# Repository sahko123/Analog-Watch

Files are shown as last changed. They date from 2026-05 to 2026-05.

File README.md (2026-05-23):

# Analog Watch

A watch that tells time using an analog voltmeter needle driven by a DAC. No screen. No hands. Just vibes and a carefully calibrated lookup table.

Featured in: **[I Built a Digital Watch With No Screen](https://youtu.be/faMIdIe0c6w)** (YOUTUBE LINK)

---

## What is this?

It's a watch. Technically. A Raspberry Pi Pico reads the time and drives an MCP4726 DAC, which pushes a voltage to a panel meter whose needle sweeps to represent whatever time-related concept you've most recently asked it about.

By default it shows seconds. Because why would you want to know the hours.

---

## How to read the time

Press a button.

| Button | Single Press | Double Click |
|---|---|---|
| Top | Hours | Date |
| Mid | Month | Seconds |
| Low | Day of week | — |

The needle will swing to the correct position. Stare at it. Contemplate what you've built.

---

## Repo contents

| Path | What's in it |
|---|---|
| `ANALCLOCK_REV0_5.ino` | Arduino sketch (RP2040) |
| `analclock v1/` | KiCad PCB project — main board revisions 1 & 2 |
| `analclock v1/analog_dial/` | KiCad PCB project — the meter dial board |
| `analclock v1/gerberv1/` | Gerber files for the main board |
| `analclock v1/analog_dial/analogdial1gerbers/` | Gerber files for the dial board |
| `*.svg` / `*.dxf` | Watch face artwork |
| `*.step` / `*.stl` / `*.f3d` | 3D printed parts |

---

## Calibration

The meter needle is non-linear, so the firmware uses a cubic polynomial LUT to correct for this. You can tune it over serial:

```
dac <value>      — hold needle at a fixed DAC value
max <value>      — set full-scale and rebuild the LUT
set <idx> <val>  — manually poke a LUT entry
lut              — print current LUT
tz <offset>      — set UTC offset in hours
<unix timestamp> — set the time
```

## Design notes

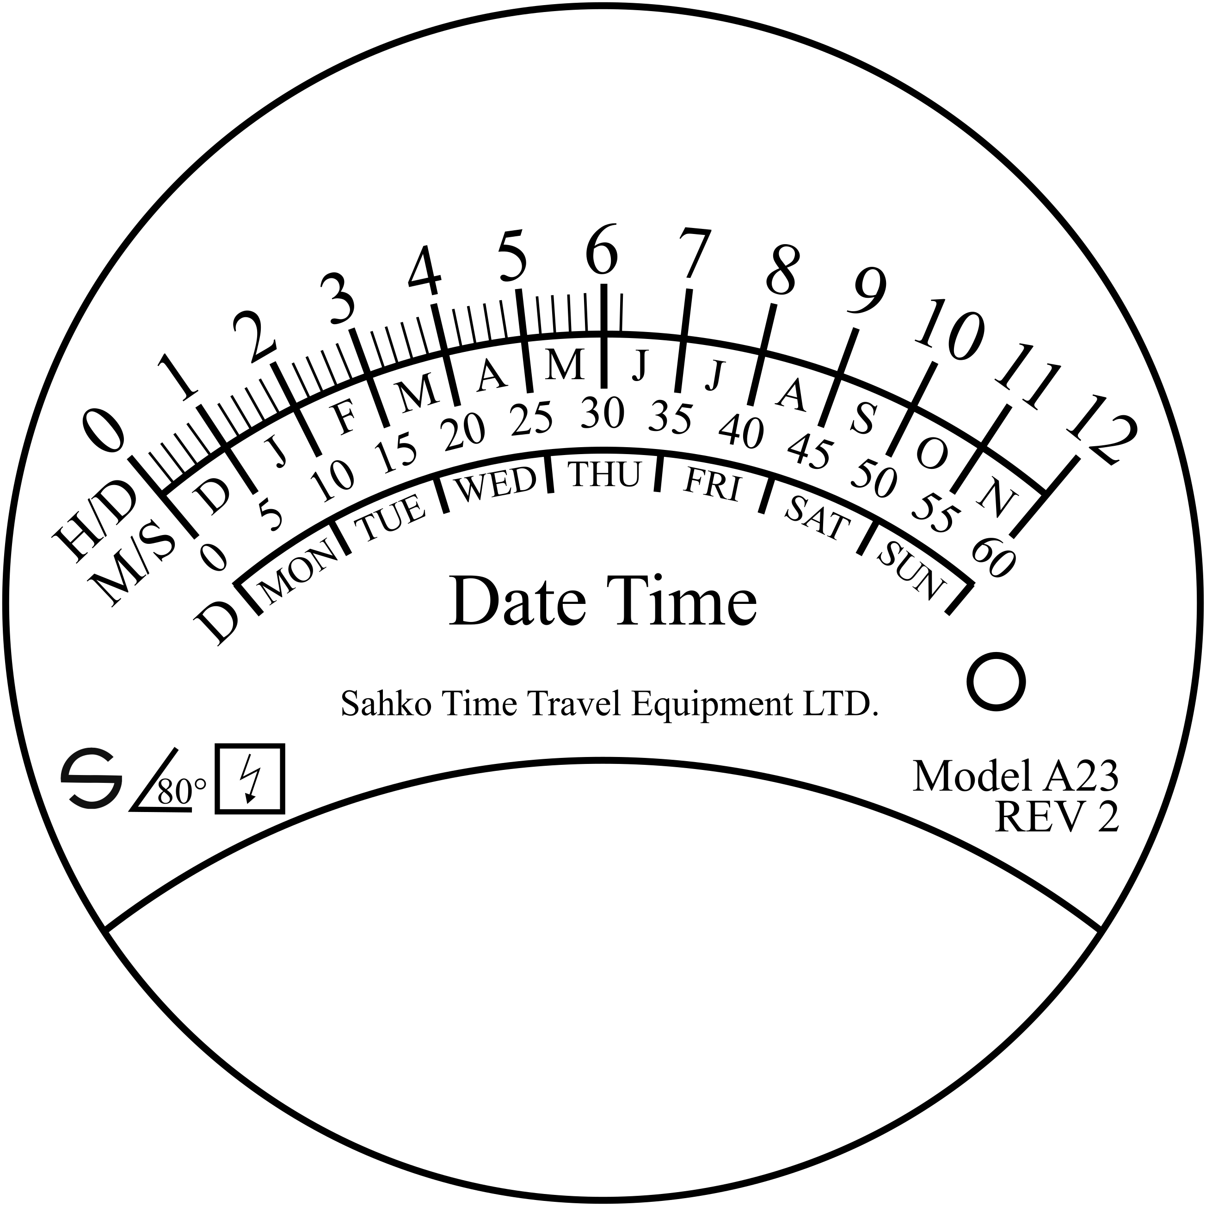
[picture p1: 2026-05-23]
analog watch 3.png

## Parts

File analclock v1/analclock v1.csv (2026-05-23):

Source: | C:\Users\Alexander Gorovenko\Desktop\Video Workbook\The Analog Watch\analclock v1\analclock v1.kicad_sch
Date: | 05/08/2023 12:25:58 AM
Tool: | Eeschema 7.0.1
Generator: | C:\Program Files\KiCad\7.0\bin\scripting\plugins/bom_csv_grouped_by_value_with_fp.py
Component Count: | 48
Ref | Qnty | Value | Cmp name | Footprint | Description | Vendor | DNP
C1, C2 | 2 | 15pF | C | Capacitor_SMD:C_0201_0603Metric_Pad0.64x0.40mm_HandSolder | Unpolarized capacitor
C3, C4, C5, C6, C7, C10, C11, C12, C13, C14, C15 | 11 | C | C | Capacitor_SMD:C_0201_0603Metric_Pad0.64x0.40mm_HandSolder | Unpolarized capacitor
C8, C9 | 2 | C | C | Capacitor_SMD:C_0402_1005Metric | Unpolarized capacitor
E1 | 1 | B+ | Conn_01x01_Pin | TestPoint:TestPoint_Pad_2.0x2.0mm | Generic connector, single row, 01x01, script generated
E2 | 1 | B- | Conn_01x01_Pin | TestPoint:TestPoint_Pad_2.0x2.0mm | Generic connector, single row, 01x01, script generated
E3 | 1 | C+ | Conn_01x01_Pin | TestPoint:TestPoint_Pad_2.0x2.0mm | Generic connector, single row, 01x01, script generated
E4 | 1 | V+ | Conn_01x01_Pin | TestPoint:TestPoint_Pad_2.0x2.0mm | Generic connector, single row, 01x01, script generated
E5 | 1 | V- | Conn_01x01_Pin | TestPoint:TestPoint_Pad_2.0x2.0mm | Generic connector, single row, 01x01, script generated
E6, E7, E8, E9, E10, E11 | 6 | ~ | Conn_01x01_Pin | TestPoint:TestPoint_Pad_D1.0mm | Generic connector, single row, 01x01, script generated
J1 | 1 | USB_C_Receptacle_USB2.0 | USB_C_Receptacle_USB2.0 | Connector_USB:USB_C_Receptacle_GCT_USB4085 | USB 2.0-only Type-C Receptacle connector
R1, R2 | 2 | 27 | R | Resistor_SMD:R_0603_1608Metric_Pad0.98x0.95mm_HandSolder | Resistor
R3 | 1 | PROG | R | Resistor_SMD:R_0603_1608Metric_Pad0.98x0.95mm_HandSolder | Resistor
R4, R5 | 2 | R | R | Resistor_SMD:R_0603_1608Metric | Resistor
R6, R7, R8, R9 | 4 | ~ | R | Resistor_SMD:R_0402_1005Metric_Pad0.72x0.64mm_HandSolder | Resistor
SW1, SW3, SW4 | 3 | SW_Push | SW_Push | Custom:EVQP7A | Push button switch, generic, two pins
SW2 | 1 | SW_Push | SW_Push | Custom:PTS636 | Push button switch, generic, two pins
U1 | 1 | RP2040 | RP2040 | Package_DFN_QFN:QFN-56-1EP_7x7mm_P0.4mm_EP3.2x3.2mm | A microcontroller by Raspberry Pi
U2 | 1 | MCP4726 | MCP4726 | Package_TO_SOT_SMD:SOT-23-6
U3 | 1 | ~ | BMM350 | Custom:BMM350
U4, U5, U6 | 3 | ~ | AP2127 | Package_TO_SOT_SMD:TSOT-23-5
U7 | 1 | W25Q32JVSS | W25Q32JVSS | Custom:uson8 | 32Mb Serial Flash Memory, Standard/Dual/Quad SPI, SOIC-8
Y2 | 1 | Crystal_GND24 | Crystal_GND24 | PCM_Crystal_Handsoldering_AKL:Crystal_SMD_Abracon_ABM8G-4Pin_3.2x2.5mm | Four pin crystal, GND on pins 2 and 4

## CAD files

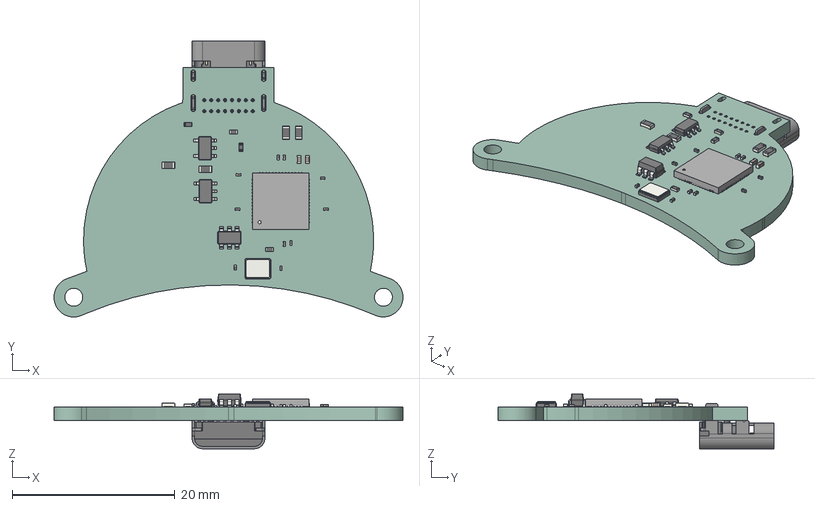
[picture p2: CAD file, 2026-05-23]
analclock v1/analclock v1.step
42.8 x 33.9 x 6.70 mm
R_0603_1608Metric x 4
QFN_56_1EP_7x7mm_P04mm_EP32x32mm
C_0201_0603Metric x 10
TSOT_23_5 x 2
C_0402_1005Metric x 2
Crystal_SMD_Abracon_ABM8G-4Pin_3.2x2.5mm
SOT_23_6
R_0402_1005Metric x 4
USB_C_Receptacle_GCT_USB4085
analclock v1_PCB

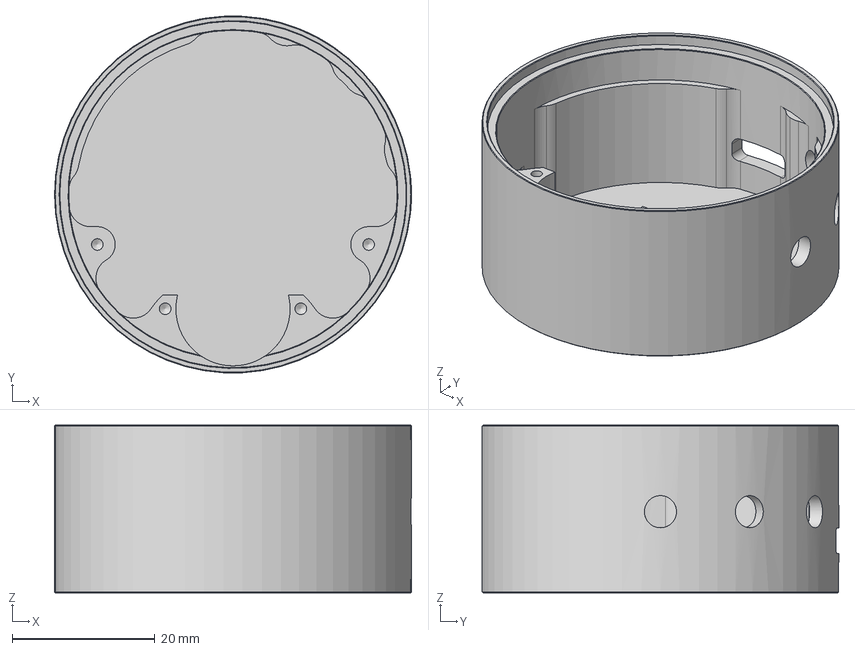
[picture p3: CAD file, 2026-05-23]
analog clock v2.step
50.0 x 49.9 x 23.5 mm

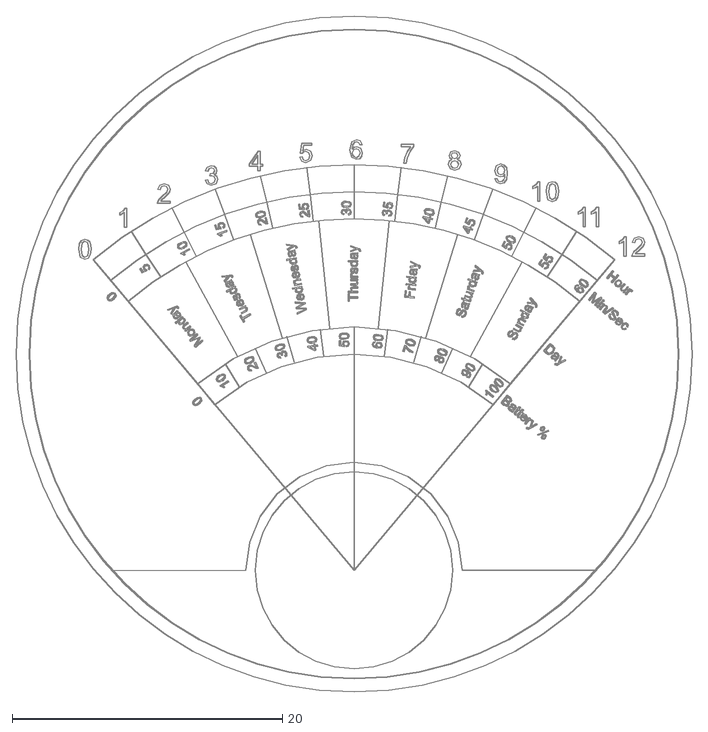
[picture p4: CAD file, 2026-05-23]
anal watch.dxf
50.0 x 50.0

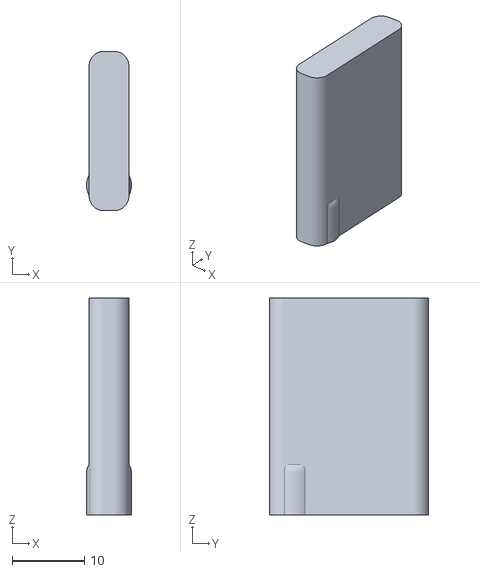
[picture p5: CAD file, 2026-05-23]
analclock v1/finger shim v4.stl
6.20 x 22.0 x 30.0

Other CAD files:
analclock v1/analog clock v2.stl
analclock v1/finger shim v4.f3d

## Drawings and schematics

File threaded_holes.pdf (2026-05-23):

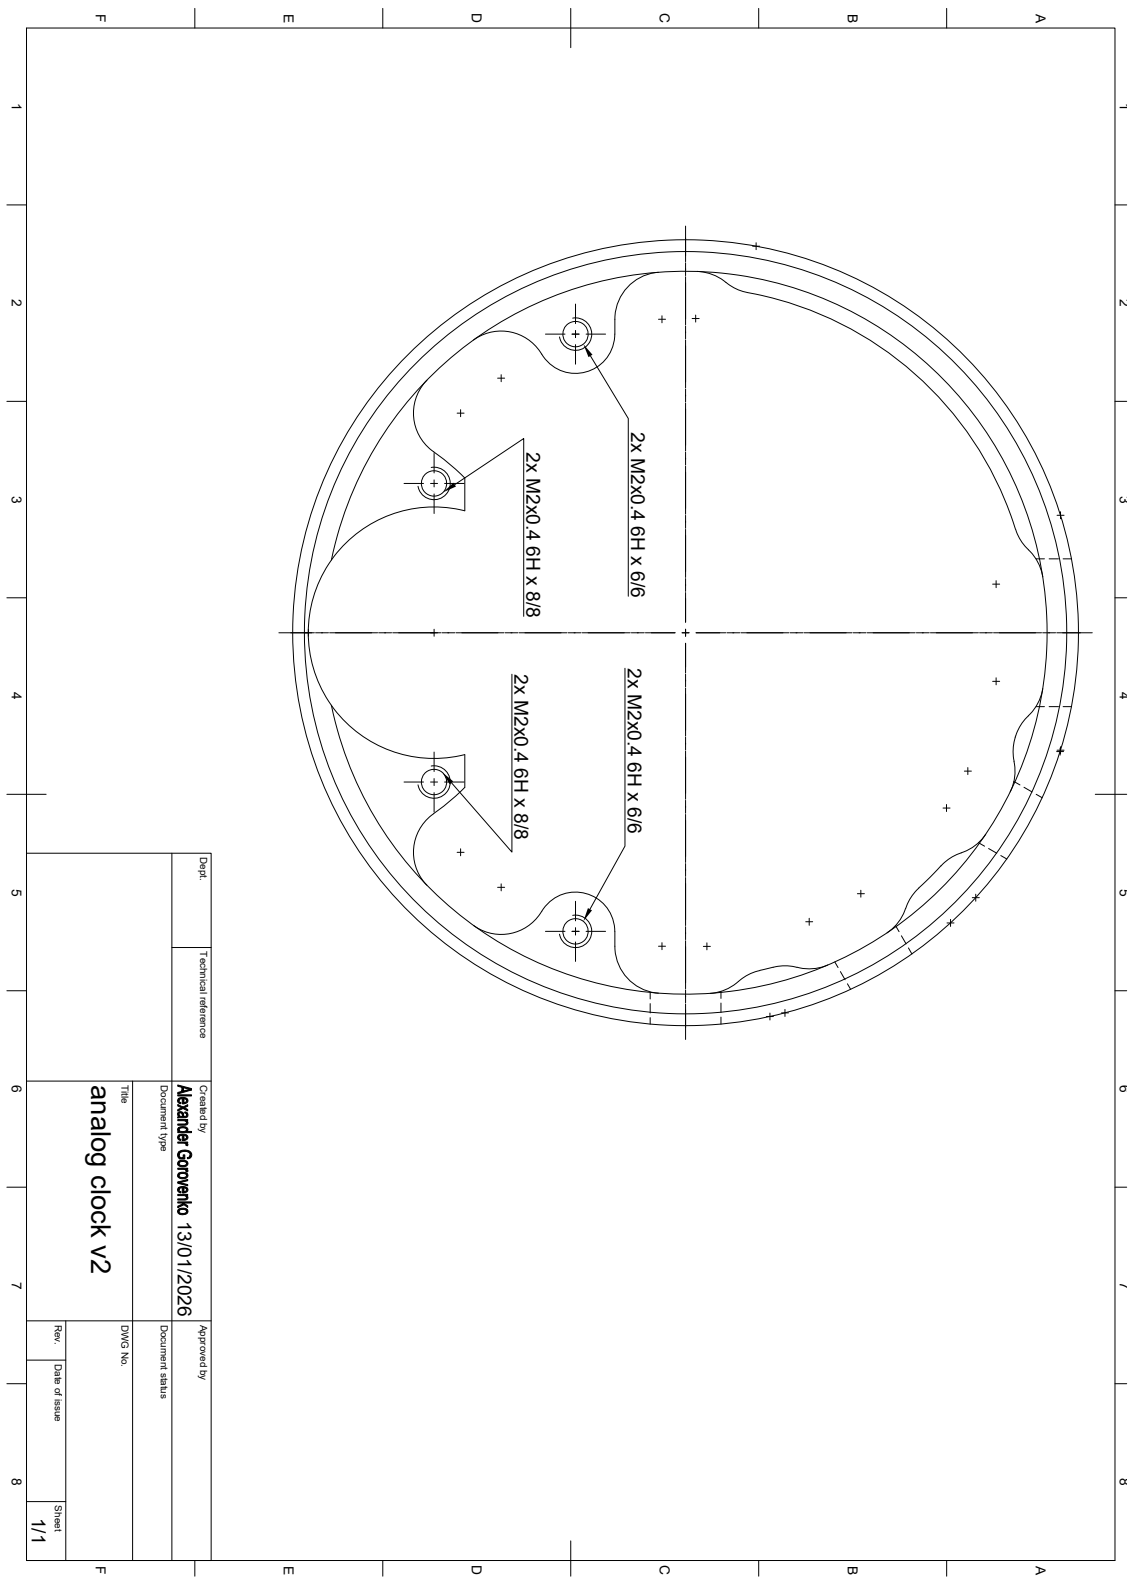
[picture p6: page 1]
analog clock v2

Dept. Technical reference Created by Approved by

Title DWG No.

Document type Document status

Rev. Date of issue Sheet

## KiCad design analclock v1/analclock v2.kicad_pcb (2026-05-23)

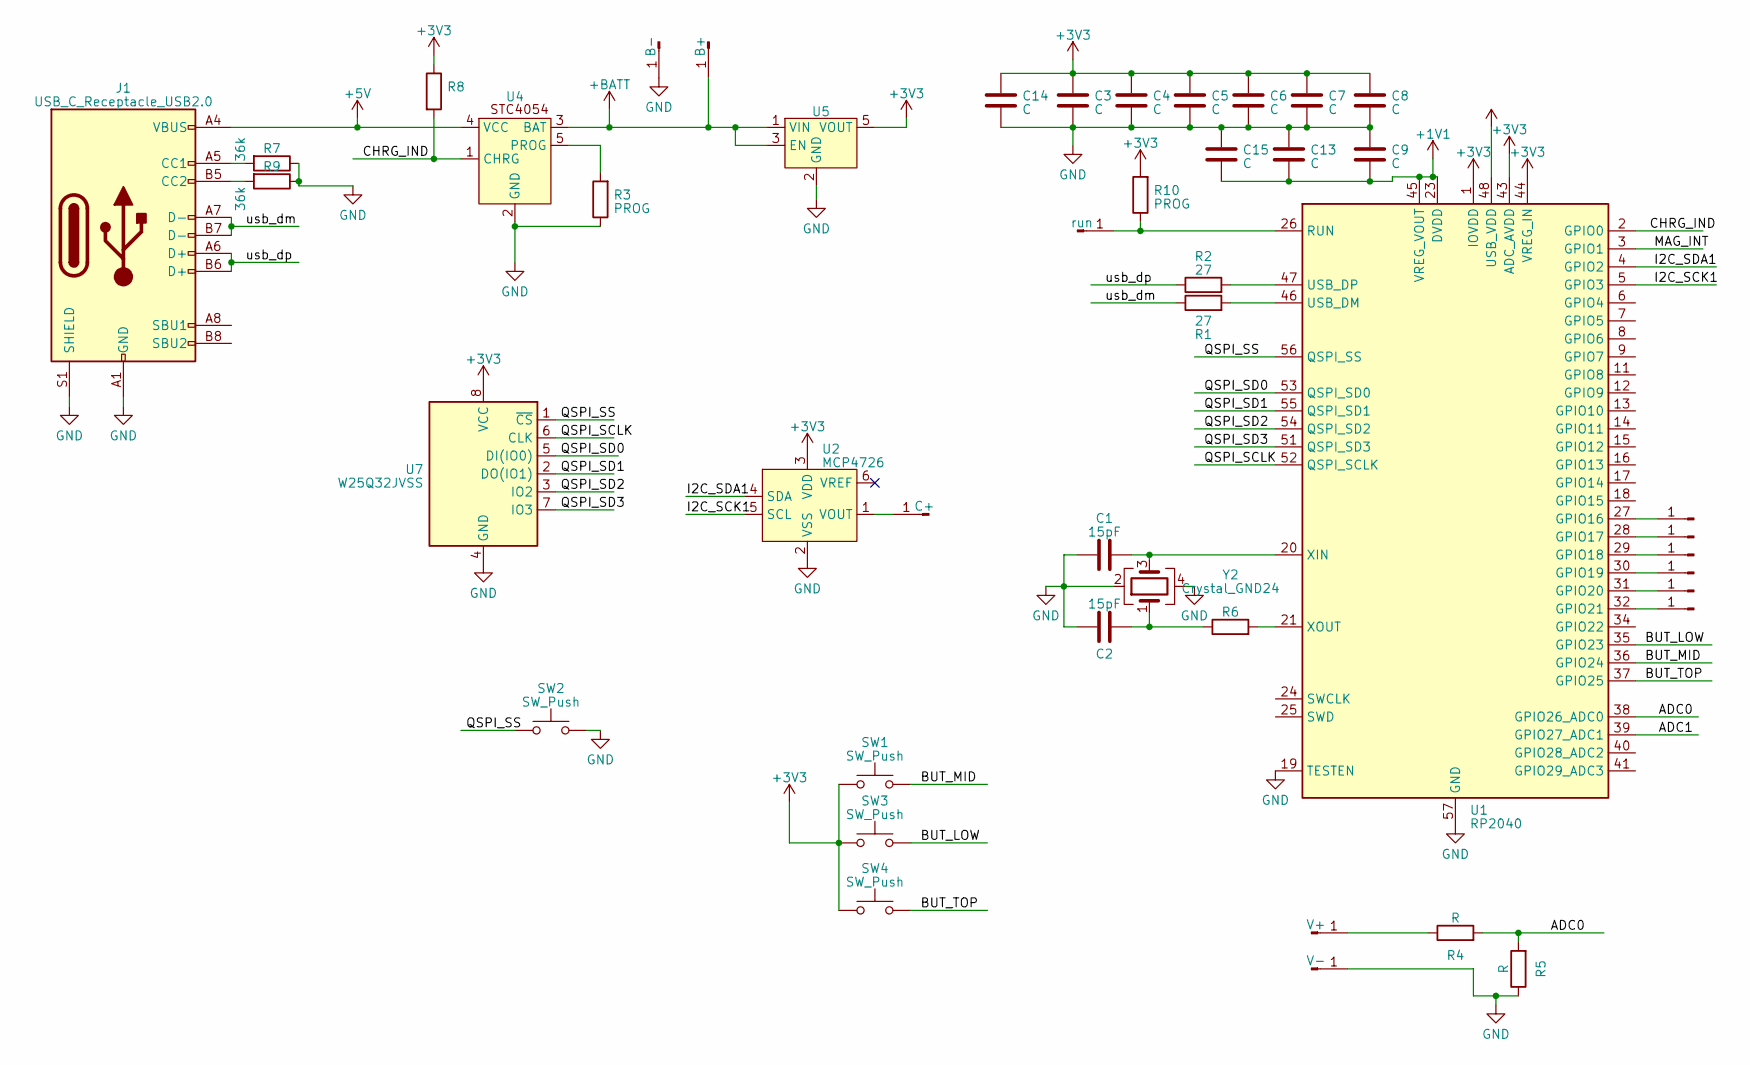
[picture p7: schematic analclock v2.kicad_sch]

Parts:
C1, C2: 15pF; C_0201_0603Metric_Pad0.64x0.40mm_HandSolder
C3, C4, C5, C6, C7, C13, C14, C15: C; C_0201_0603Metric_Pad0.64x0.40mm_HandSolder
C8, C9: C; C_0402_1005Metric
E1: B+; TestPoint_Pad_2.0x2.0mm
E2: B-; TestPoint_Pad_2.0x2.0mm
E3: C+; TestPoint_Pad_2.0x2.0mm
E4: V+; TestPoint_Pad_2.0x2.0mm
E5: V-; TestPoint_Pad_2.0x2.0mm
E6, E7, E8, E9, E10, E11: TestPoint_Pad_D1.0mm
E12: run; TestPoint_Pad_2.0x2.0mm
J1: USB_C_Receptacle_USB2.0; USB_C_Receptacle_GCT_USB4085
R1, R2: 27; R_0603_1608Metric_Pad0.98x0.95mm_HandSolder
R3, R10: PROG; R_0603_1608Metric_Pad0.98x0.95mm_HandSolder
R4, R5: R; R_0603_1608Metric
R6, R8: R_0402_1005Metric_Pad0.72x0.64mm_HandSolder
R7, R9: 36k; R_0402_1005Metric_Pad0.72x0.64mm_HandSolder
SW1, SW3, SW4: SW_Push; EVQP7A
SW2: SW_Push; PTS636
U1: RP2040; QFN-56-1EP_7x7mm_P0.4mm_EP3.2x3.2mm
U2: MCP4726; SOT-23-6
U4, U5: TSOT-23-5
U7: W25Q32JVSS; uson8
Y2: Crystal_GND24; Crystal_SMD_Abracon_ABM8G-4Pin_3.2x2.5mm

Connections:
+1V1: C9.2, C13.2, C15.2, U1.23 (DVDD), U1.45 (VREG_VOUT), U1.50 (DVDD)
+3V3: C3.1, C4.1, C5.1, C6.1, C7.1, C8.1, C14.1, R8.1, R10.2, SW1.1, SW3.1, SW4.1, U1.1 (IOVDD), U1.10 (IOVDD), U1.22 (IOVDD), U1.33 (IOVDD), U1.42 (IOVDD), U1.43 (ADC_AVDD), U1.44 (VREG_IN), U1.48 (USB_VDD), U1.49 (IOVDD), U2.3 (VDD), U5.5 (VOUT), U7.8 (VCC); also elsewhere on the board
+5V: J1.A4 (VBUS), J1.A9 (VBUS), J1.B4 (VBUS), J1.B9 (VBUS), U4.4 (VCC)
+BATT: E1.1, U4.3 (BAT), U5.1 (VIN), U5.3 (EN); also elsewhere on the board
/ADC0: R4.2, R5.2, U1.38 (GPIO26_ADC0)
/ADC1: U1.39 (GPIO27_ADC1)
/BUT_LOW: SW3.2, U1.35 (GPIO23)
/BUT_MID: SW1.2, U1.36 (GPIO24)
/BUT_TOP: SW4.2, U1.37 (GPIO25)
/CHRG_IND: R8.2, U1.2 (GPIO0), U4.1 (CHRG)
/I2C_SCK1: U1.5 (GPIO3), U2.5 (SCL); also elsewhere on the board
/I2C_SDA1: U1.4 (GPIO2), U2.4 (SDA); also elsewhere on the board
/MAG_INT: U1.3 (GPIO1); also elsewhere on the board
/QSPI_SCLK: U1.52 (QSPI_SCLK), U7.6 (CLK)
/QSPI_SD0: U1.53 (QSPI_SD0), U7.5 (DI(IO0))
/QSPI_SD1: U1.55 (QSPI_SD1), U7.2 (DO(IO1))
/QSPI_SD2: U1.54 (QSPI_SD2), U7.3 (IO2)
/QSPI_SD3: U1.51 (QSPI_SD3), U7.7 (IO3)
/QSPI_SS: SW2.1, U1.56 (QSPI_SS), U7.1 (~CS)
/usb_dm: J1.A7 (D-), J1.B7 (D-), R1.1
/usb_dp: J1.A6 (D+), J1.B6 (D+), R2.1
GND: C1.1, C2.1, C3.2, C4.2, C5.2, C6.2, C7.2, C8.2, C9.1, C13.1, C14.2, C15.1, E2.1, E5.1, J1.A1 (GND), J1.A12 (GND), J1.B1 (GND), J1.B12 (GND), J1.S1 (SHIELD), R3.1, R5.1, R7.1, R9.1, SW2.2, U1.19 (TESTEN), U1.57 (GND), U2.2 (VSS), U4.2 (GND), U5.2 (GND), U7.4 (GND), Y2.2, Y2.4; also elsewhere on the board
unnamed: C2.2, R6.1, Y2.1
unnamed: E3.1, U2.1 (VOUT)
unnamed: E4.1, R4.1
unnamed: E6.1, U1.32 (GPIO21)
unnamed: E7.1, U1.31 (GPIO20)
unnamed: E8.1, U1.30 (GPIO19)
unnamed: E9.1, U1.29 (GPIO18)
unnamed: E10.1, U1.28 (GPIO17)
unnamed: E11.1, U1.27 (GPIO16)
unnamed: E12.1, R10.1, U1.26 (RUN)
unnamed: J1.A5 (CC1), R7.2
unnamed: J1.B5 (CC2), R9.2
unnamed: R1.2, U1.46 (USB_DM)
unnamed: R2.2, U1.47 (USB_DP)
unnamed: C1.2, U1.20 (XIN), Y2.3
unnamed: R6.2, U1.21 (XOUT)
unnamed: R3.2, U4.5 (PROG)

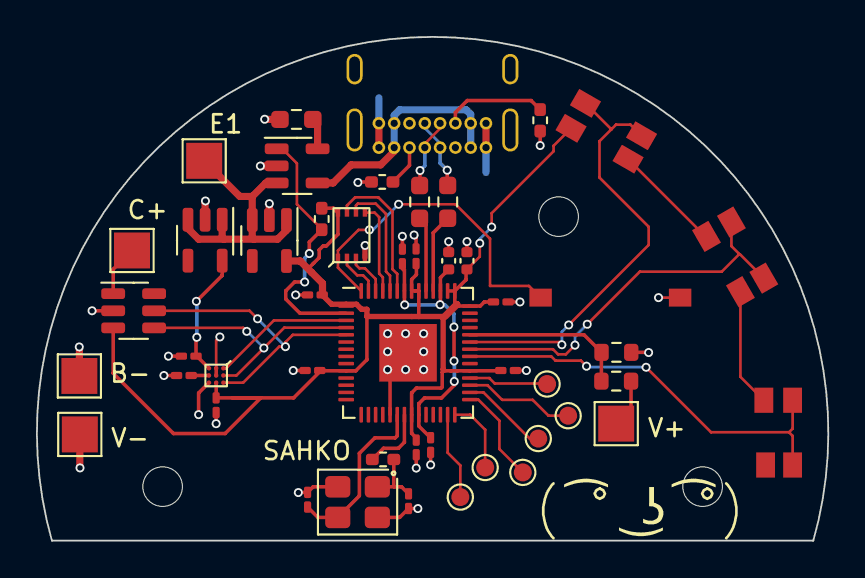
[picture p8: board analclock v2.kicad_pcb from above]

Board: 2 copper layers, 44.0 x 28.0 mm, 48 parts (1 on the bottom side), 39 nets.

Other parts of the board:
C10, C11, C12: C; C_0201_0603Metric_Pad0.64x0.40mm_HandSolder
U3: BMM350
U6: TSOT-23-5

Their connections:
+1V8: C10.1, U3.C1 (VDD), U6.5 (VOUT)
+3V3: C11.1, U3.B3 (VDDIO); also elsewhere on the board
+BATT: U6.1 (VIN), U6.3 (EN); also elsewhere on the board
/I2C_SCK1: U3.A3 (SCK); also elsewhere on the board
/I2C_SDA1: U3.A2 (SDA); also elsewhere on the board
/MAG_INT: U3.A1 (INT); also elsewhere on the board
GND: C10.2, C11.2, C12.1, U3.B1 (GND), U3.B2 (ADSEL), U3.C3 (BYPASS), U6.2 (GND); also elsewhere on the board
unnamed: C12.2, U3.C2 (CRST)

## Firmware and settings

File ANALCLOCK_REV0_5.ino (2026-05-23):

#include <Wire.h>
#include <MCP4726_wire1.h>
#include <math.h>
#include "time.h"
#include "sys/time.h"

MCP4726 dac;

int current_timezone_offset = 1; // hours offset from UTC

// Cubic shape: v = A*x + B*x^2 + C*x^3,  A+B+C=1 (exact endpoints)
// Least-squares fit to measured points: 0%=0, 25%=555, 50%=960, 75%=1555, 100%=2650
#define LUT_A  1.107f
#define LUT_B -1.416f
#define LUT_C  1.309f   // = 1 - A - B
#define LUT_SIZE 13

uint16_t meter_lut[LUT_SIZE];
const int lut_size = LUT_SIZE;

void buildLUT(uint16_t maxValue) {
  for (int i = 0; i < LUT_SIZE; i++) {
    float x = (float)i / (LUT_SIZE - 1);
    float v = LUT_A * x + LUT_B * x * x + LUT_C * x * x * x;
    meter_lut[i] = (uint16_t)(maxValue * v);
  }
}

unsigned long lastUpdate = 0;
bool usePowerFit = false;

// Buttons: active high, external pull-down, high-impedance input
#define BTN_LOW 23
#define BTN_MID 24
#define BTN_TOP 25

enum DisplayMode { MODE_SECONDS, MODE_HOURS, MODE_DATE, MODE_MONTH, MODE_DOW, MODE_STATIC_DAC };
DisplayMode displayMode = MODE_SECONDS;
uint16_t    staticDacValue = 0;

const unsigned long DEBOUNCE_MS     = 20;  // switch bounce < 10ms; 20ms is safe
const unsigned long DOUBLE_CLICK_MS = 1500;

// Rising-edge debounce: accepts a press only if it arrives >= DEBOUNCE_MS after
// the previous accepted press. Release state is ignored, which avoids the failure
// mode where a quick re-press arrives before the release debounce clears.
struct Button {
  uint8_t       pin;
  bool          lastRaw;
  unsigned long lastEdgeTime;

  void begin(uint8_t p) {
    pin          = p;
    lastRaw      = false;
    lastEdgeTime = 0;
  }

  // Returns true once per physical press.
  bool risingEdge(unsigned long now) {
    bool raw  = digitalRead(pin);
    bool edge = false;
    if (raw && !lastRaw && now - lastEdgeTime >= DEBOUNCE_MS) {
      lastEdgeTime = now;
      edge         = true;
    }
    lastRaw = raw;
    return edge;
  }
};

Button btnTop, btnMid, btnLow;

// Double-click tracking
static unsigned long topLastPress  = 0;
static int           topPressCount = 0;
static unsigned long midLastPress  = 0;
static int           midPressCount = 0;

uint16_t getInterpolatedDAC(float percent);
uint16_t getPowerFitDAC(float percent);

void setup() {
  Serial.begin(115200);
  Wire1.setSDA(2);
  Wire1.setSCL(3);
  Wire1.begin();
  dac.begin(0x61);
  buildLUT(2650);

  pinMode(BTN_LOW, INPUT);
  pinMode(BTN_MID, INPUT);
  pinMode(BTN_TOP, INPUT);

  btnTop.begin(BTN_TOP);
  btnMid.begin(BTN_MID);
  btnLow.begin(BTN_LOW);

  dac.setVoltage(0);

  struct timeval tv;
  tv.tv_sec = 1611198855; // Jan 21, 2021  3:14:15AM — RPi Pico release
  tv.tv_usec = 0;
  settimeofday(&tv, nullptr);
}

void loop() {
  // Serial handler
  if (Serial.available()) {
    String input = Serial.readStringUntil('\n');
    input.trim();

    if (input == "bootloader") {
      rp2040.rebootToBootloader();

    } else if (input == "reset") {
      rp2040.reboot();

    } else if (input == "lut") {
      // Print current LUT values
      Serial.print("meter_lut[] = {");
      for (int i = 0; i < LUT_SIZE; i++) {
        Serial.print(meter_lut[i]);
        if (i < LUT_SIZE - 1) Serial.print(", ");
      }
      Serial.println("};");

    } else if (input.startsWith("tz ")) {
      current_timezone_offset = input.substring(3).toInt();
      Serial.print("Timezone offset = ");
      Serial.println(current_timezone_offset);

    } else if (input.startsWith("dac ")) {
      // Hold needle at a fixed value for calibration: "dac 2048"
      staticDacValue = (uint16_t)input.substring(4).toInt();
      displayMode    = MODE_STATIC_DAC;
      Serial.print("Static DAC = ");
      Serial.println(staticDacValue);

    } else if (input.startsWith("max ")) {
      // Set full-scale max and rebuild LUT via cubic: "max 3500"
      uint16_t newMax = (uint16_t)input.substring(4).toInt();
      buildLUT(newMax);
      Serial.print("max=");
      Serial.print(newMax);
      Serial.println(", LUT rebuilt");

    } else if (input.startsWith("set ")) {
      // Set a single LUT entry: "set 6 1100"
      int space = input.indexOf(' ', 4);
      if (space > 0) {
        int   idx = input.substring(4, space).toInt();
        uint16_t val = (uint16_t)input.substring(space + 1).toInt();
        if (idx >= 0 && idx < LUT_SIZE) {
          meter_lut[idx] = val;
          Serial.print("lut[");
          Serial.print(idx);
          Serial.print("] = ");
          Serial.println(val);
        } else {
          Serial.println("index out of range");
        }
      }

    } else {
      // Treat as Unix timestamp
      time_t newTime = (time_t)input.toInt() + (current_timezone_offset * 3600);
      struct timeval tv = { .tv_sec = newTime, .tv_usec = 0 };
      settimeofday(&tv, nullptr);
      Serial.print("Time set to: ");
      Serial.println(newTime);
    }
  }

  unsigned long now = millis();

  // Top button: single press = hours, double click within 1.5s = date
  if (btnTop.risingEdge(now)) {
    if (topPressCount > 0 && now - topLastPress < DOUBLE_CLICK_MS) {
      displayMode   = MODE_DATE;
      topPressCount = 0;
      Serial.println("Mode: DATE");
    } else {
      topPressCount = 1;
      topLastPress  = now;
      displayMode   = MODE_HOURS;
      Serial.println("Mode: HOURS");
    }
  }

  // Mid button: single press = month, double click within 1.5s = seconds
  if (btnMid.risingEdge(now)) {
    if (midPressCount > 0 && now - midLastPress < DOUBLE_CLICK_MS) {
      displayMode   = MODE_SECONDS;
      midPressCount = 0;
      Serial.println("Mode: SECONDS");
    } else {
      midPressCount = 1;
      midLastPress  = now;
      displayMode   = MODE_MONTH;
      Serial.println("Mode: MONTH");
    }
  }

  // Low button: press = day of week
  if (btnLow.risingEdge(now)) {
    displayMode = MODE_DOW;
    Serial.println("Mode: DAY_OF_WEEK");
  }

  // 200ms display update
  if (now - lastUpdate >= 200) {
    lastUpdate += 200;

    // Static calibration mode: hold needle at a fixed DAC value
    if (displayMode == MODE_STATIC_DAC) {
      dac.setVoltage(staticDacValue);
      Serial.print("STATIC DAC = ");
      Serial.println(staticDacValue);
      return;
    }

    time_t epochNow;
    time(&epochNow);
    struct tm* t = localtime(&epochNow);

    float percent;

    switch (displayMode) {

      case MODE_HOURS: {
        int h = t->tm_hour % 12;
        if (h == 0) {
          percent = t->tm_min / 60.0;  // 12 o'clock hour: sweep minutes across full scale
        } else {
          percent = (h + t->tm_min / 60.0) / 12.0;
        }
        Serial.print("HOURS ");
        Serial.print(h == 0 ? 12 : h);
        Serial.print(":");
        if (t->tm_min < 10) Serial.print("0");
        Serial.print(t->tm_min);
        break;
      }

      case MODE_DATE: {
        percent = t->tm_mday / 60.0;  // day 1–31 on the 0–60 seconds scale
        Serial.print("DATE ");
        Serial.print(t->tm_mday);
        break;
      }

      case MODE_MONTH: {
        // Dec→Nov order: Dec(tm_mon=11)=idx 0, Jan(0)=idx 1 … Nov(10)=idx 11
        int idx = (t->tm_mon + 1) % 12;
        percent = (idx + 0.5) / 12.0;
        const char* labels[] = {"D","J","F","M","A","M","J","J","A","S","O","N"};
        Serial.print("MONTH ");
        Serial.print(labels[idx]);
        break;
      }

      case MODE_DOW: {
        // Mon→Sun order: tm_wday Mon=1…Sat=6,Sun=0 → idx 0–6
        int idx = (t->tm_wday + 6) % 7;
        percent = (idx + 0.5) / 7.0;
        const char* labels[] = {"Mon","Tue","Wed","Thu","Fri","Sat","Sun"};
        Serial.print("DOW ");
        Serial.print(labels[idx]);
        break;
      }

      case MODE_SECONDS:
      default: {
        percent = t->tm_sec / 60.0;
        Serial.print("SEC ");
        Serial.print(t->tm_sec);
        break;
      }
    }

    uint16_t dacValue = usePowerFit ? getPowerFitDAC(percent) : getInterpolatedDAC(percent);
    dac.setVoltage(dacValue);
    Serial.print(" → DAC = ");
    Serial.println(dacValue);
  }
}

// Interpolation between LUT values (with gamma smoothing)
uint16_t getInterpolatedDAC(float percent) {
  percent = constrain(percent, 0.0, 1.0);
  float position = percent * (lut_size - 1);
  int   index    = (int)position;
  float t        = position - index;
  t = pow(t, 1.5);
  if (index >= lut_size - 1) return meter_lut[lut_size - 1];
  uint16_t start = meter_lut[index];
  uint16_t end   = meter_lut[index + 1];
  return (uint16_t)(start + (end - start) * t);
}

// Power-law fitted model (from your full calibration curve)
uint16_t getPowerFitDAC(float percent) {
  percent = constrain(percent, 0.0, 1.0);
  return (uint16_t)(2940.06 * pow(percent, 1.40));
}
